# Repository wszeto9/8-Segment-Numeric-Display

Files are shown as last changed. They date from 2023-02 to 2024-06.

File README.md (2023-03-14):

# 8 Segment Numeric DIsplay

A 10W/digit numeric display to show numbers in any room. Designed for MIT 2.007's Spring gameboard. 

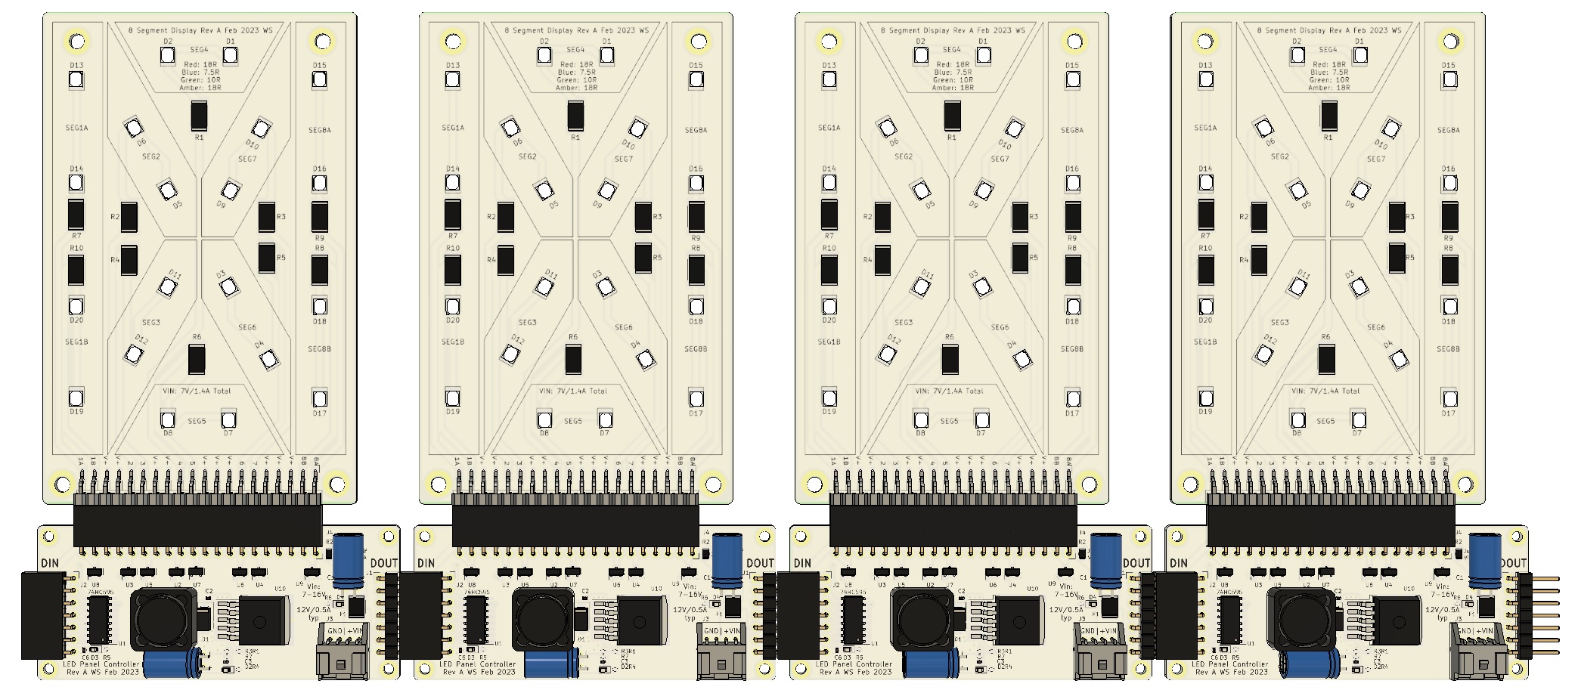
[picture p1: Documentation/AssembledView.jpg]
AssembledView


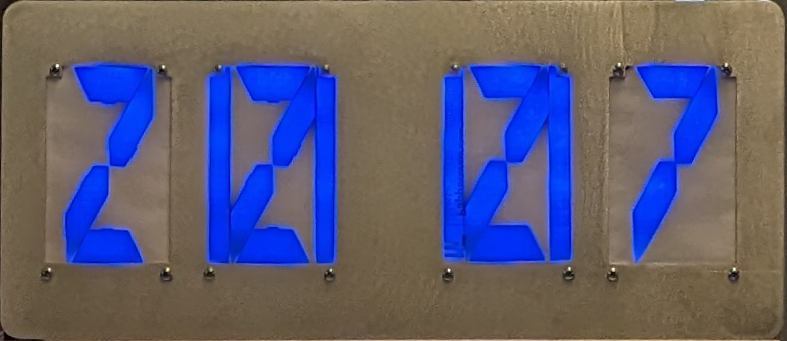
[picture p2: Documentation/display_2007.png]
2.007 Display

Display showing 2.007

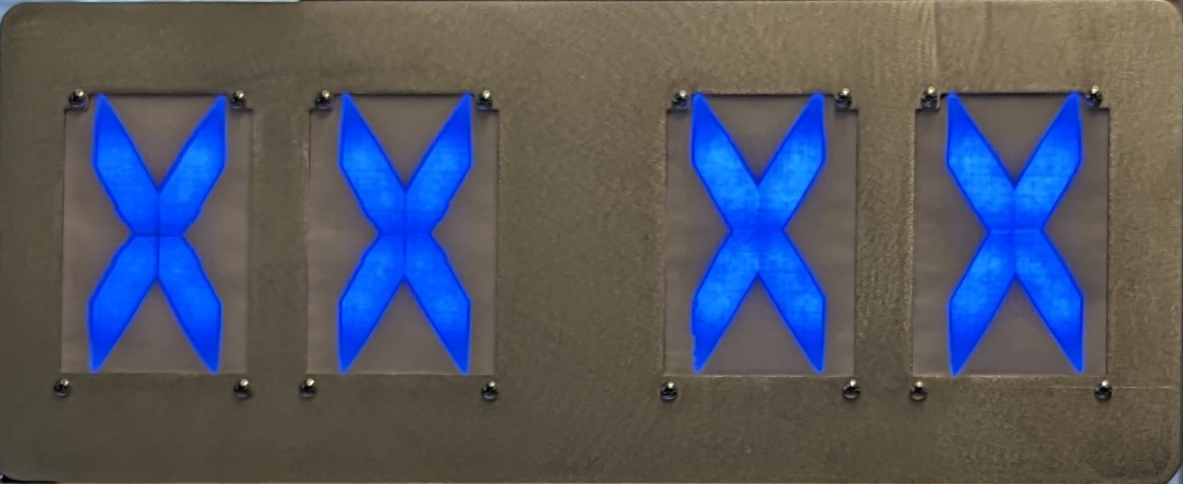
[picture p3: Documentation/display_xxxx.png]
xxxx Display

Display showing xx xx

[Interactive BOM for LED Display](https://htmlpreview.github.io/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)

[Interactive BOM for LED Display Controller](https://htmlpreview.github.io/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)

[Schematic for LED Display](https://github.com/wszeto9/8-Segment-Numeric-Display/blob/main/Documentation/LED_Panel_Sch.pdf)

[Schematic for LED Display Controller](https://github.com/wszeto9/8-Segment-Numeric-Display/blob/main/Documentation/LED_Panel_Controller_Sch.pdf)

The display is a 65mm x 102mm single layer aluminum PCB. It has a 1x20 SMT male header in order to connect a driver board. The display requires active cooling for duty cycles above 50%. 

The driver is a 75mm x 32mm double layer FR4 PCB. It relies on a 74HC595 shift register to drive a chain of displays using a single data stream. The driving microcontroller can send 3.3V or 5V logic. The logic level is set by the reference voltage on the input. The driver has an onboard buck converter to create the drive voltage of the display. The board can receive 7-28VDC (Peak current draw is 10W/Vin). 
 
# Driving Logic

- Pull nCLR high in order to prevent an accidential clear
- Use SRCLK and SER to send a data packet to the first number's data packet on the right (with LSB first)
- Repeat sending data until all numbers are sent.
- Pulse RCLK to push shifted bits into the outputs
- Use PWM on nOE to adjust the display brightness. Note: The brightness will lower with higher duty cycles.

|Number to display| Data packet|
|--|--|
|0|0b10111011|
|1|0b00000011|
|2|0b00111010|
|3|0b00011110|
|4|0b01000110|
|5|0b01011100|
|6|0b00101110|
|7|0b00110010|
|8|0b01111110|
|9|0b01110010|

# Ordering the LED Panel Parts

From Digikey: quantities are for 1x LED panel.

1x S1113E-20-ND

In addition,

**Red:**

- 20x 90-JE2835ARD-N-0001A0000-N0000001TR-ND

- 10x RMCF2512JT18R0CT-ND

**Blue:**

- 20x  90-JE2835ABL-N-0005A0000-N0000001CT-ND

- 10x 118-CRM2512-JW-6R8ELFCT-ND

**Yellow:**

- 20x 90-JE2835APA-N-0001A0000-N0000001CT-ND
- 10x RMCF2512JT18R0CT-ND

**Green:**
- 20x 90-JE2835AGR-N-0002A0000-N0000001CT-ND
- 10x RMCF2512JT10R0CT-ND

Resistance values for colors:

- Red: For 140mA (25.2lm/led) use 18R
- Amber: For 140mA (24.8lm/led) use 18R
- Green: For 140mA (65.5lm/led) use 10R
- Blue: For 140mA (16.5lm/led) use 6.8R

# Ordering the LED Panel Controller Parts

**Digikey Parts**
|Quantity|Digikey PN| Description|
|--|--|--|
|1|1189-3657-ND|120uF/35V Capacitor|
|1|399-ESK337M016AE3AA-ND|330uF/16V Capacitor|
|1|F3375CT-ND|2A Polyfuse|
|1|455-1849-ND|JST PA 1x04 RA Housing|
|1|455-2753-ND|JST PA 1x04 Connector|
|4|455-1325-1-ND|JST PA Crimp|
|1|1292-WR08X000PTLCT-ND|0805 Jumper|

**Amazon Parts**

- 1x [1x20 female pin socket](https://www.amazon.com/Yohii-Female-Header-2-54mm-Connector/dp/B07P1R9CGT/)

- 1x [LM2596 Buck Converter](https://www.amazon.com/gp/product/B0B63GQDJW/)

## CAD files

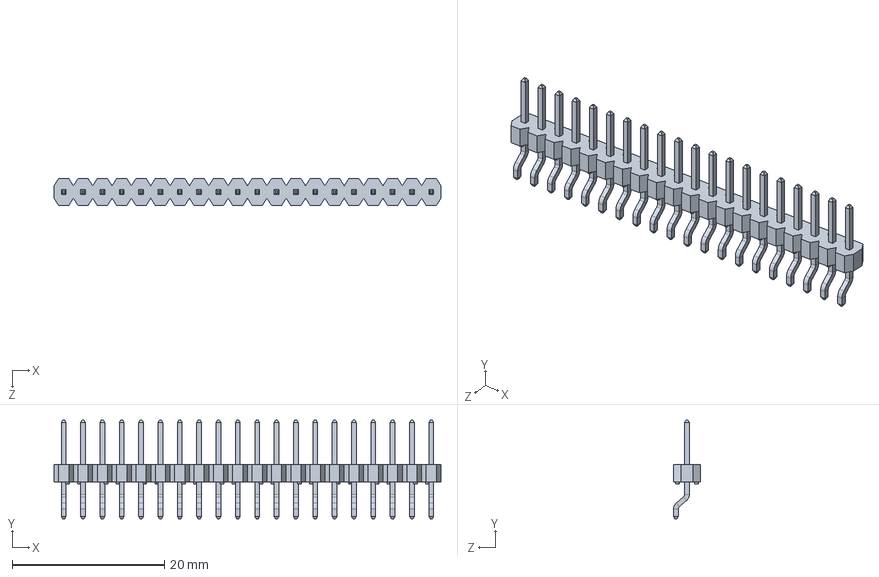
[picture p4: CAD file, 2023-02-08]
LED_Panel/C20SBSN-M89.step
50.8 x 13.0 x 3.56 mm

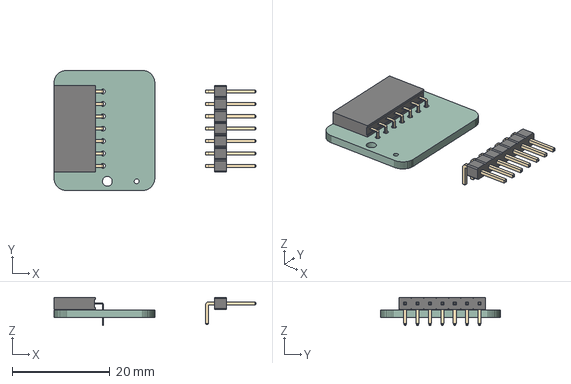
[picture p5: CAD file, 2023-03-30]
Spacer/Spacer.step
41.4 x 24.6 x 5.84 mm
PCB

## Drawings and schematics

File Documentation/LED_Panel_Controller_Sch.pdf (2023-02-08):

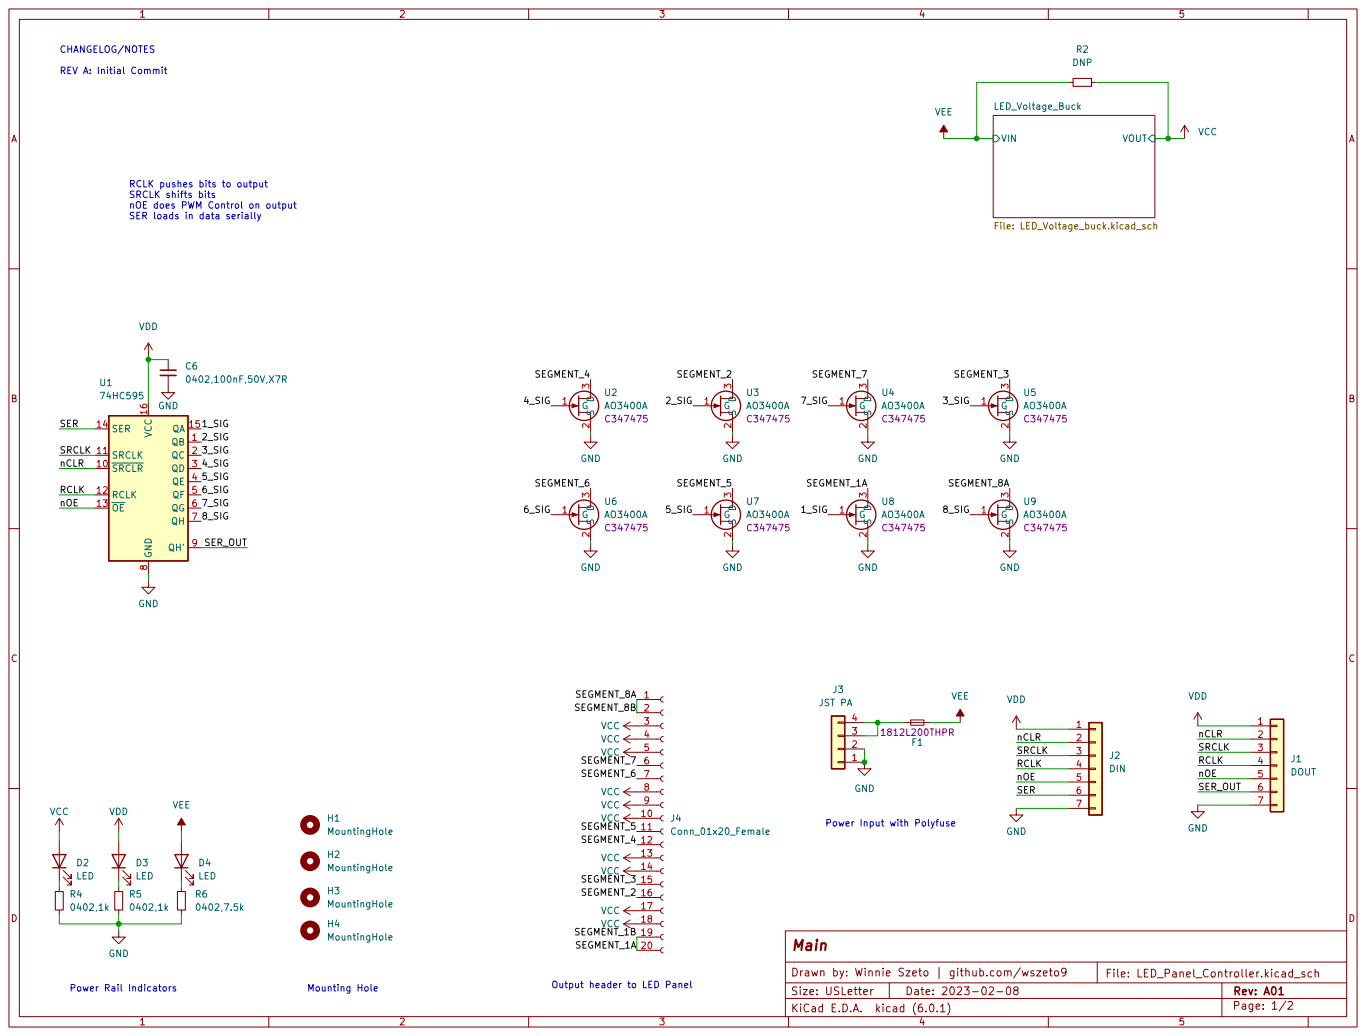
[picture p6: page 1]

CHANGELOG/NOTES REV A: Initial Commit

RCLK pushes bits to output SRCLK shifts bits nOE does PWM Control on output

SER loads in data serially
SEGMENT_5 SEGMENT_1B

Power Input with Polyfuse

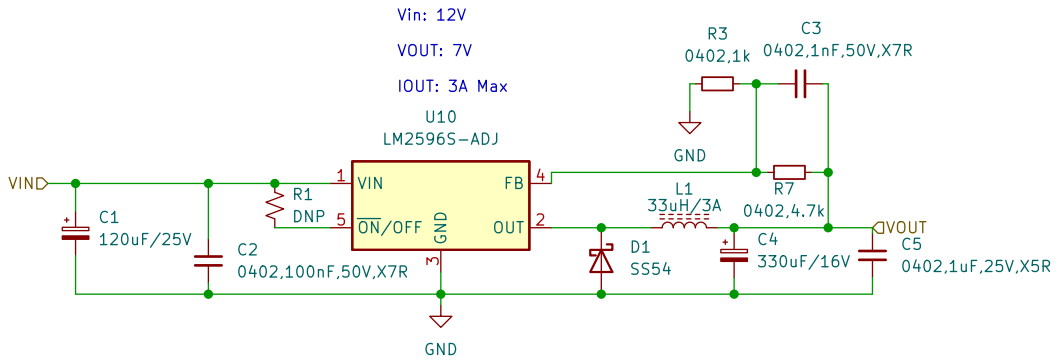
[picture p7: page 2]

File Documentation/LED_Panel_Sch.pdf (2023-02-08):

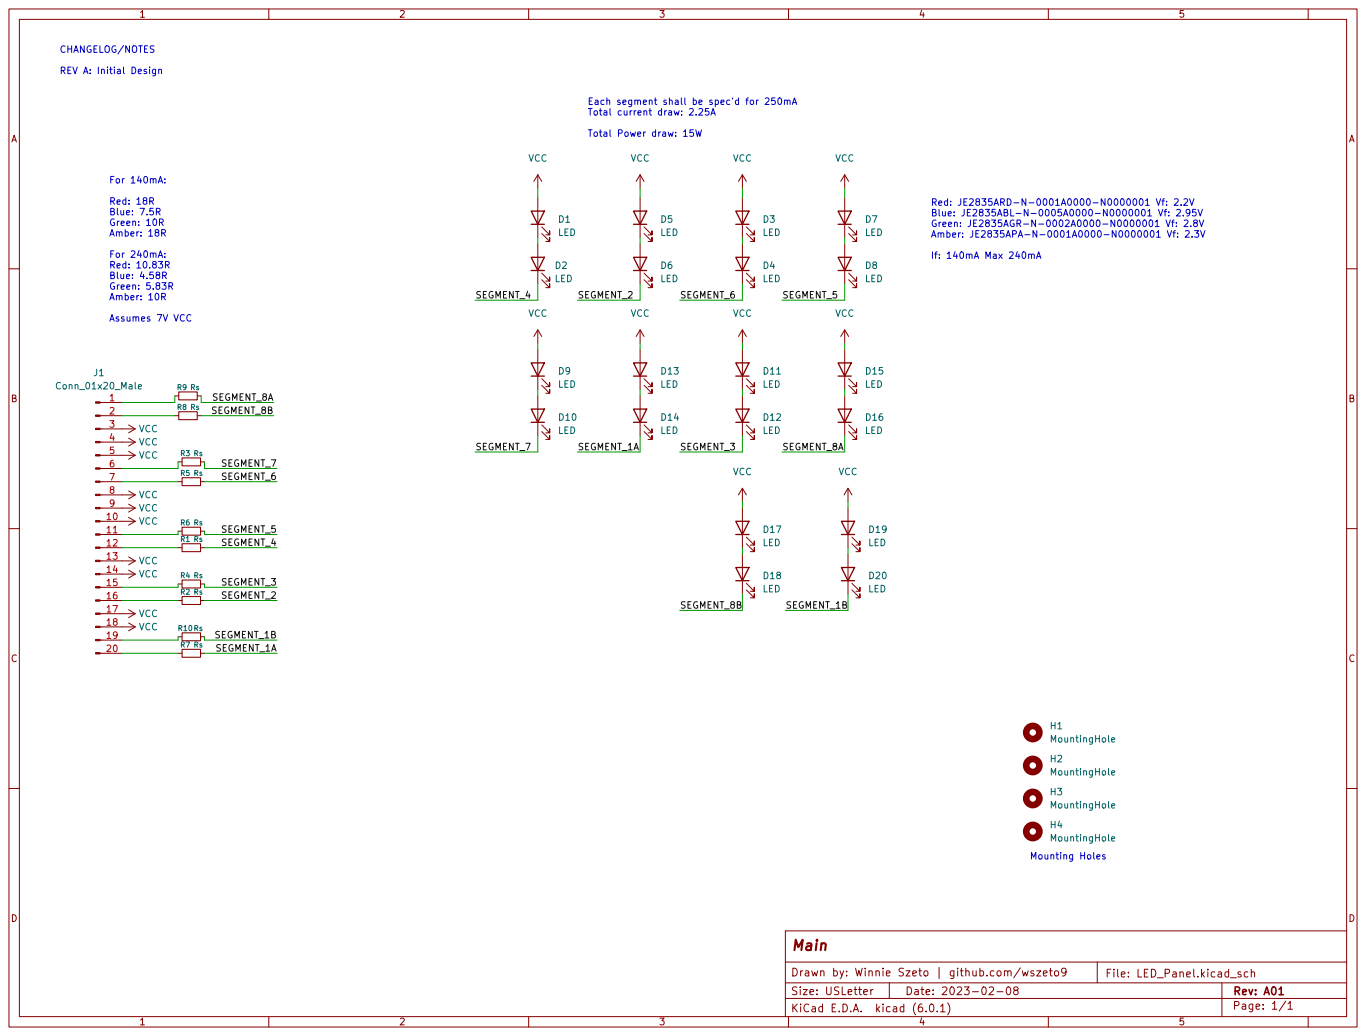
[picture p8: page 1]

CHANGELOG/NOTES REV A: Initial Design For 140mA: Red: 18R

Each segment shall be spec'd for 250mA
Total current draw: 2.25A
If: 140mA Max 240mA Mounting Holes

Red: JE2835ARD-N-0001A0000-N0000001 Vf: 2.2V
Blue: JE2835ABL-N-0005A0000-N0000001 Vf: 2.95V Green: JE2835AGR-N-0002A0000-N0000001 Vf: 2.8V

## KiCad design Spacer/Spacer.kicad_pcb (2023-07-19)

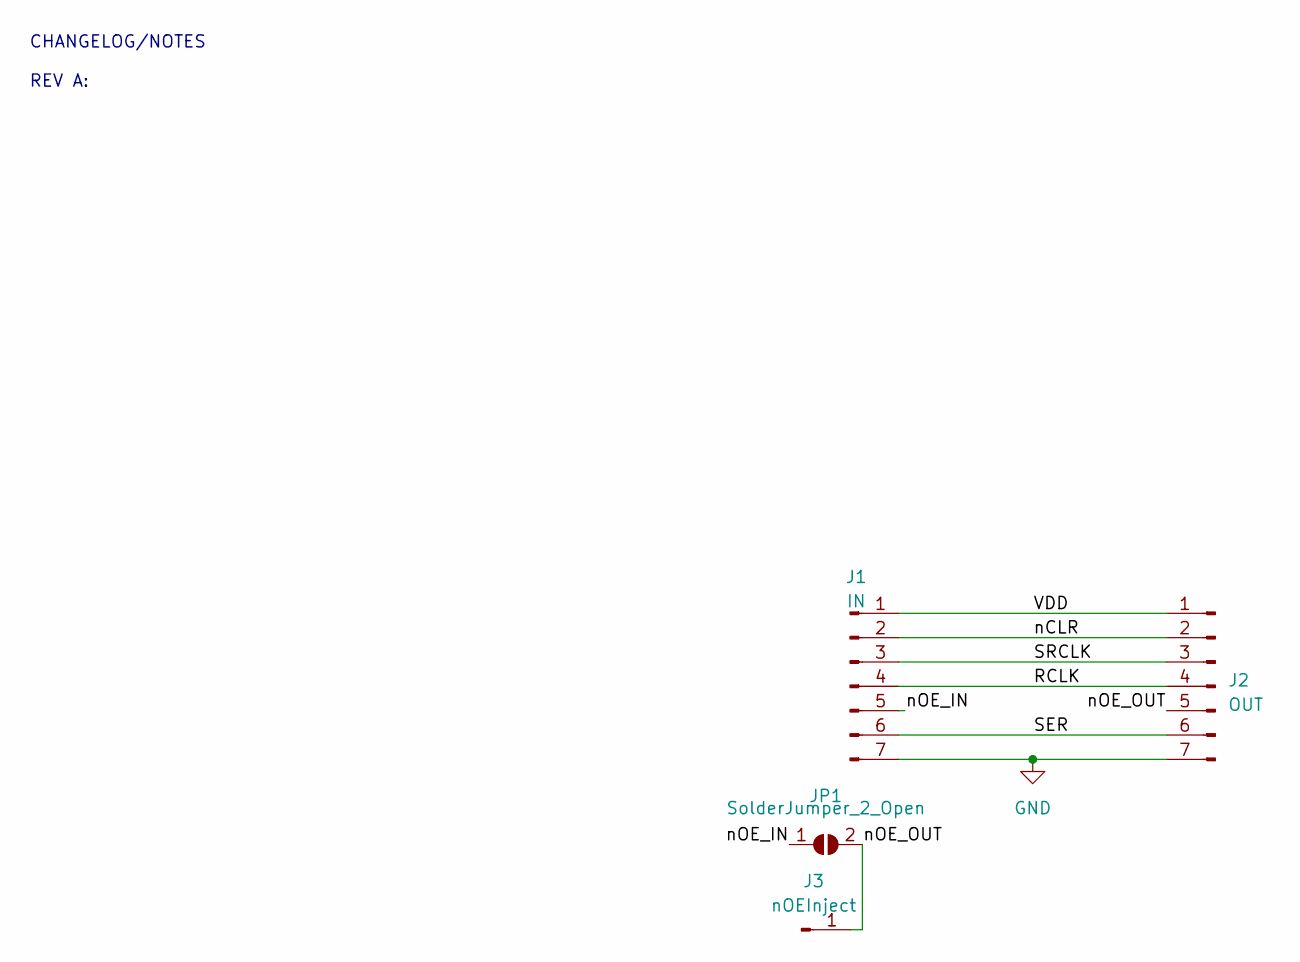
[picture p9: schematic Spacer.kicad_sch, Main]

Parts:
J1: IN; PinSocket_1x07_P2.54mm_Horizontal
J2: OUT; PinHeader_1x07_P2.54mm_Horizontal
J3: nOEInject; SolderWire-0.1sqmm_1x01_D0.4mm_OD1mm_Relief2x
JP1: SolderJumper_2_Open; SolderJumper-2_P1.3mm_Open_TrianglePad1.0x1.5mm

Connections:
/RCLK: J1.4, J2.4
/SER: J1.6, J2.6
/SRCLK: J1.3, J2.3
/VDD: J1.1, J2.1
/nCLR: J1.2, J2.2
/nOE_IN: J1.5, JP1.1 (A)
/nOE_OUT: J2.5, J3.1, JP1.2 (B)
GND: J1.7, J2.7

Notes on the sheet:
CHANGELOG/NOTES REV A:

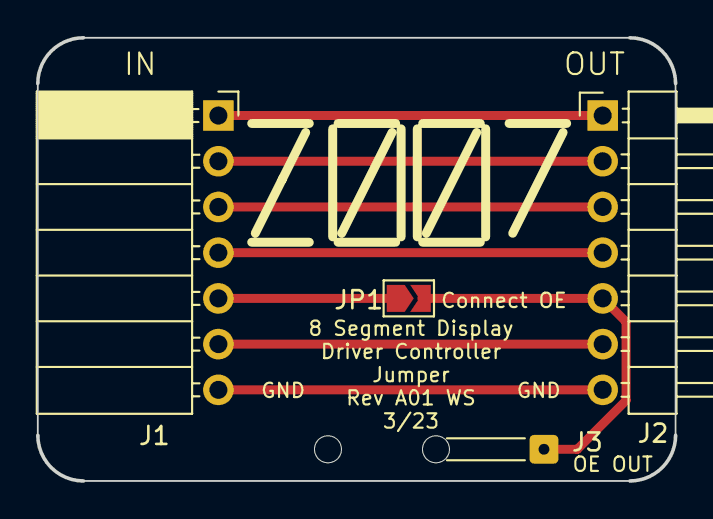
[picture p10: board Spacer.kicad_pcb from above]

Board: 2 copper layers, 35.4 x 24.6 mm, 4 parts (0 on the bottom side), 8 nets.

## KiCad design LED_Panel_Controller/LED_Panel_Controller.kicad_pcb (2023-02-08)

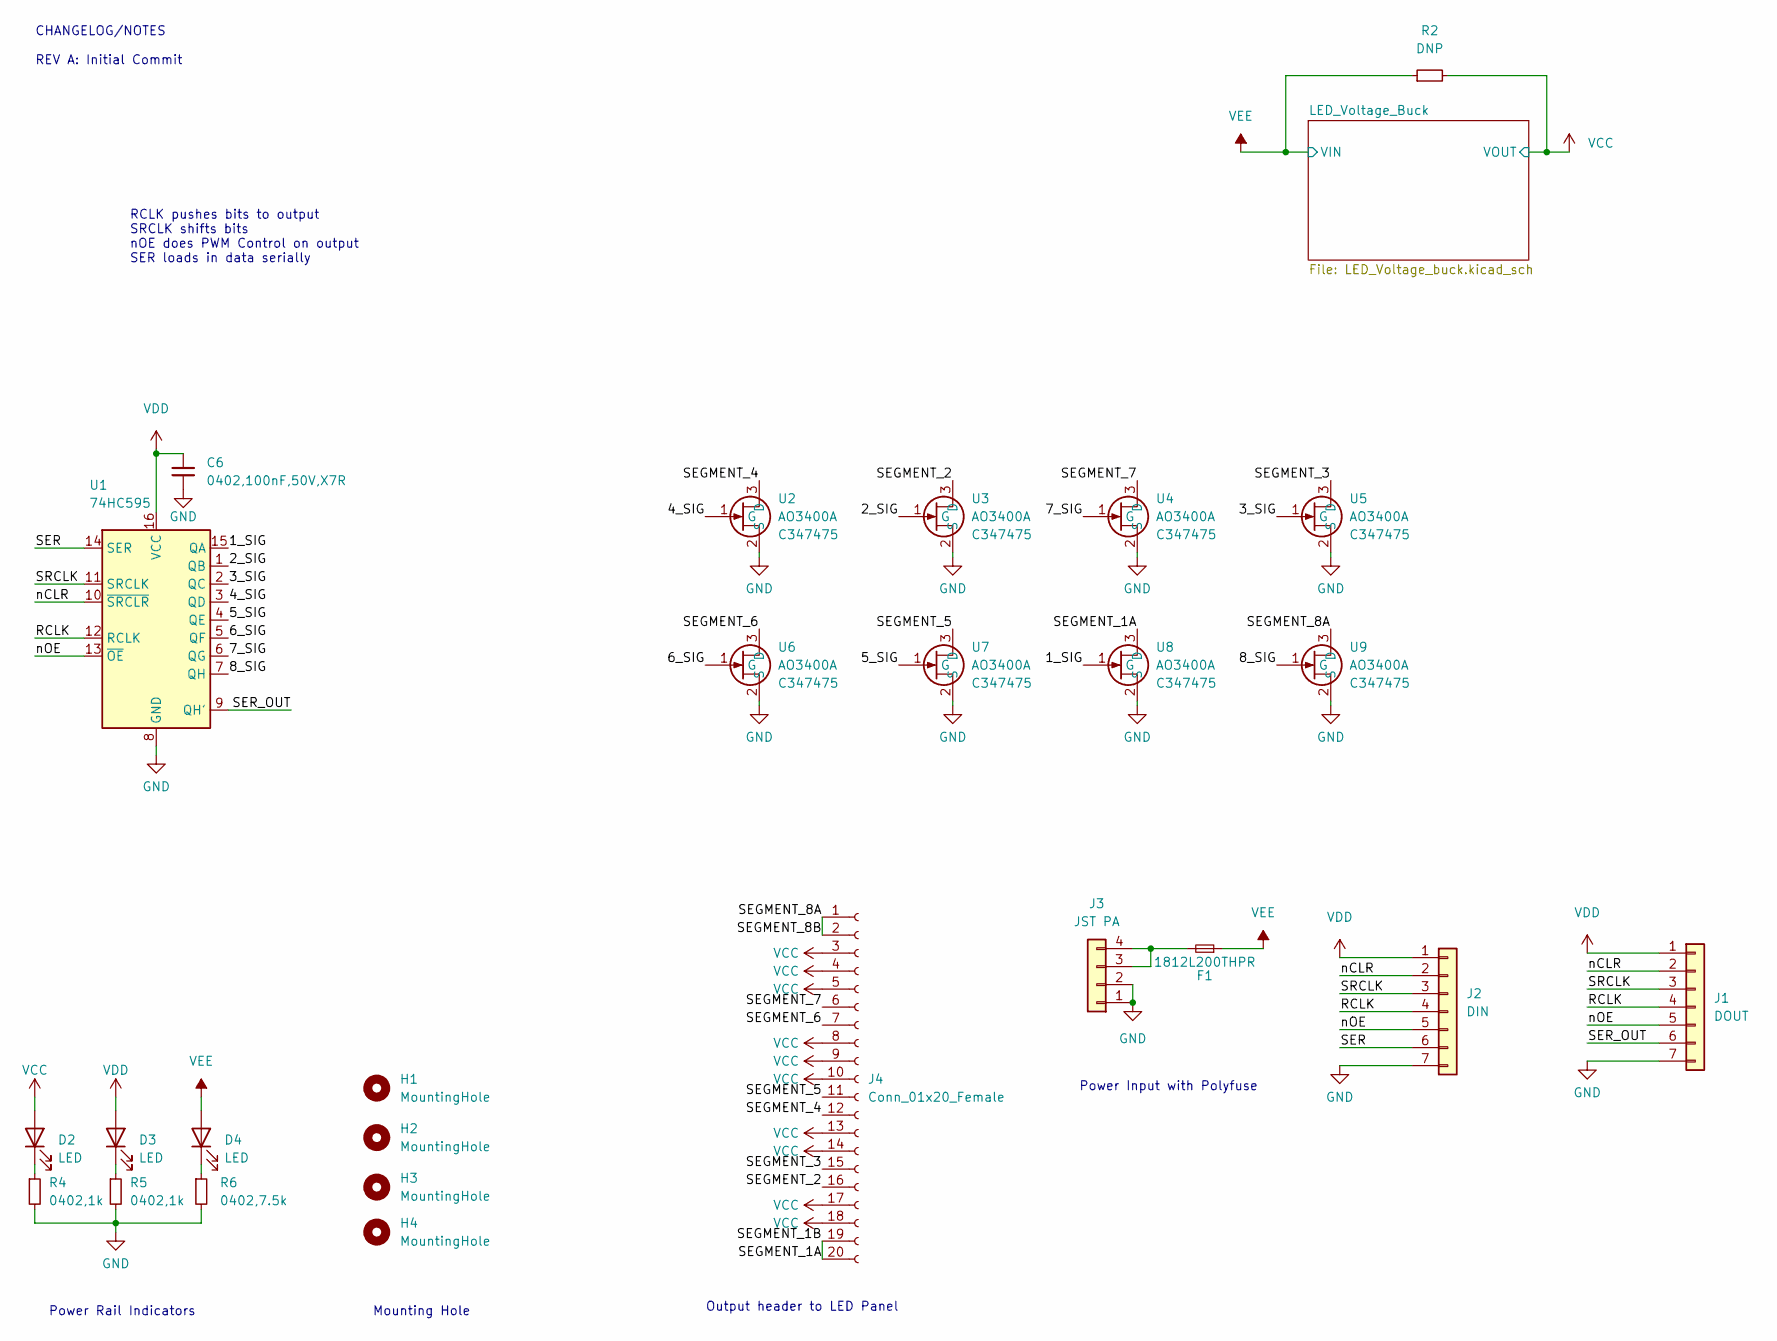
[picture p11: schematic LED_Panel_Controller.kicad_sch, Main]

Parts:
C6: 0402,100nF,50V,X7R; C_0402_1005Metric; MFGPN CL05B104KB54PNC; LCSC C307331
D2, D3, D4: LED; LED_0603_1608Metric; LCSC C2290
F1: 3A; Fuse_1812_4532Metric; MFGPN 1812L200THPR; Digikey F3375CT-ND
H1, H2, H3, H4: MountingHole; MountingHole_2.2mm_M2_DIN965_Pad
J1: DOUT; PinHeader_1x07_P2.54mm_Horizontal
J2: DIN; PinSocket_1x07_P2.54mm_Horizontal
J3: JST PA; JST_S04B-PASK-2(LF)(SN); Digikey 455-1849-ND
J4: Conn_01x20_Female; PinSocket_1x20_P2.54mm_Horizontal
R2: DNP; R_0805_2012Metric
R4, R5: 0402,1k; R_0402_1005Metric; MFGPN 0402WGF1001TCE; LCSC C11702
R6: 0402,7.5k; R_0402_1005Metric; MFGPN 0402WGF7501TCE; LCSC C25918
U1: 74HC595; SOIC-16_3.9x9.9mm_P1.27mm; MFGPN CD74HC595M96; LCSC C5947
U2, U3, U4, U5, U6, U7, U8, U9: AO3400A; SOT-23; LCSC C347475

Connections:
/1_SIG: U1.15 (QA), U8.1 (G)
/2_SIG: U1.1 (QB), U3.1 (G)
/3_SIG: U1.2 (QC), U5.1 (G)
/4_SIG: U1.3 (QD), U2.1 (G)
/5_SIG: U1.4 (QE), U7.1 (G)
/6_SIG: U1.5 (QF), U6.1 (G)
/7_SIG: U1.6 (QG), U4.1 (G)
/8_SIG: U1.7 (QH), U9.1 (G)
/RCLK: J1.4, J2.4, U1.12 (RCLK)
/SEGMENT_1A: J4.19, J4.20, U8.3 (D)
/SEGMENT_2: J4.16, U3.3 (D)
/SEGMENT_3: J4.15, U5.3 (D)
/SEGMENT_4: J4.12, U2.3 (D)
/SEGMENT_5: J4.11, U7.3 (D)
/SEGMENT_6: J4.7, U6.3 (D)
/SEGMENT_7: J4.6, U4.3 (D)
/SEGMENT_8A: J4.1, J4.2, U9.3 (D)
/SER: J2.6, U1.14 (SER)
/SER_OUT: J1.6, U1.9 (QH')
/SRCLK: J1.3, J2.3, U1.11 (SRCLK)
/nCLR: J1.2, J2.2, U1.10 (~SRCLR)
/nOE: J1.5, J2.5, U1.13 (~OE)
GND: C6.2, J1.7, J2.7, J3.1, J3.2, R4.2, R5.2, R6.2, U1.8 (GND), U2.2 (S), U3.2 (S), U4.2 (S), U5.2 (S), U6.2 (S), U7.2 (S), U8.2 (S), U9.2 (S); also elsewhere on the board
unnamed: D2.1 (K), R4.1
unnamed: D3.1 (K), R5.1
unnamed: D4.1 (K), R6.1
unnamed: F1.2, J3.3, J3.4
VCC: D2.2 (A), J4.3, J4.4, J4.5, J4.8, J4.9, J4.10, J4.13, J4.14, J4.17, J4.18, R2.2; also elsewhere on the board
VDD: C6.1, D3.2 (A), J1.1, J2.1, U1.16 (VCC)
VEE: D4.2 (A), F1.1, R2.1; also elsewhere on the board

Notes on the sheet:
Power Input with Polyfuse
RCLK pushes bits to output SRCLK shifts bits nOE does PWM Control on output SER loads in data serially
Mounting Hole
Output header to LED Panel
Power Rail Indicators
CHANGELOG/NOTES REV A: Initial Commit

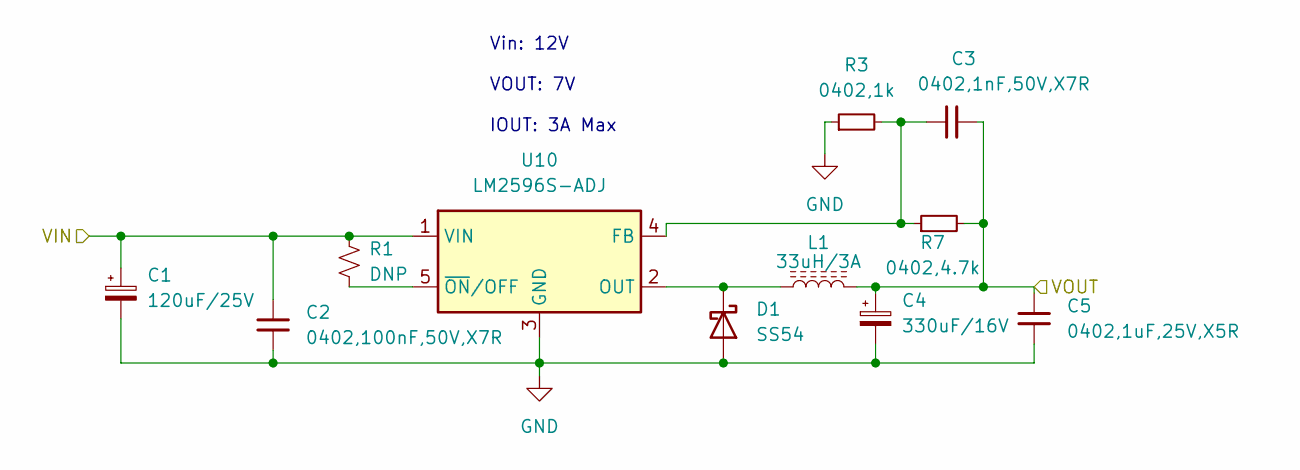
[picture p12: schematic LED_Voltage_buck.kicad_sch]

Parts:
C1: 120uF/25V; C_Radial_D6.3mm_H11.0mm_P2.50mm; MFGPN 860010473009; Digikey 732-8632-1-ND
C2: 0402,100nF,50V,X7R; C_0402_1005Metric; MFGPN CL05B104KB54PNC; LCSC C307331
C3: 0402,1nF,50V,X7R; C_0402_1005Metric; MFGPN 0402B102K500NT; LCSC C1523
C4: 330uF/16V; C_Radial_D6.3mm_H11.0mm_P2.50mm; MFGPN 860020373011; Digikey 732-8798-1-ND
C5: 0402,1uF,25V,X5R; C_0402_1005Metric; MFGPN CL05A105KA5NQNC; LCSC C52923
D1: SS54; D_SMA; LCSC C22452
L1: 33uH/3A; L_10.4x10.4_H4.8; LCSC C225031
R1: DNP; R_0402_1005Metric
R3: 0402,1k; R_0402_1005Metric; MFGPN 0402WGF1001TCE; LCSC C11702
R7: 0402,4.7k; R_0402_1005Metric; MFGPN 0402WGF4701TCE; LCSC C25900
U10: LM2596S-ADJ; TO-263-5_TabPin3; MFGPN LM2596S-ADJ

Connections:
GND: C1.2, C2.2, C4.2, C5.2, D1.2 (A), R3.1, U10.3 (GND); also elsewhere on the board
unnamed: C3.1, R3.2, R7.1, U10.4 (FB)
unnamed: D1.1 (K), L1.1, U10.2 (OUT)
unnamed: R1.1, U10.5 (~ON/OFF)
VCC: C3.2, C4.1, C5.1, L1.2, R7.2; also elsewhere on the board
VEE: C1.1, C2.1, R1.2, U10.1 (VIN); also elsewhere on the board

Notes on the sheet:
Vin: 12V VOUT: 7V IOUT: 3A Max

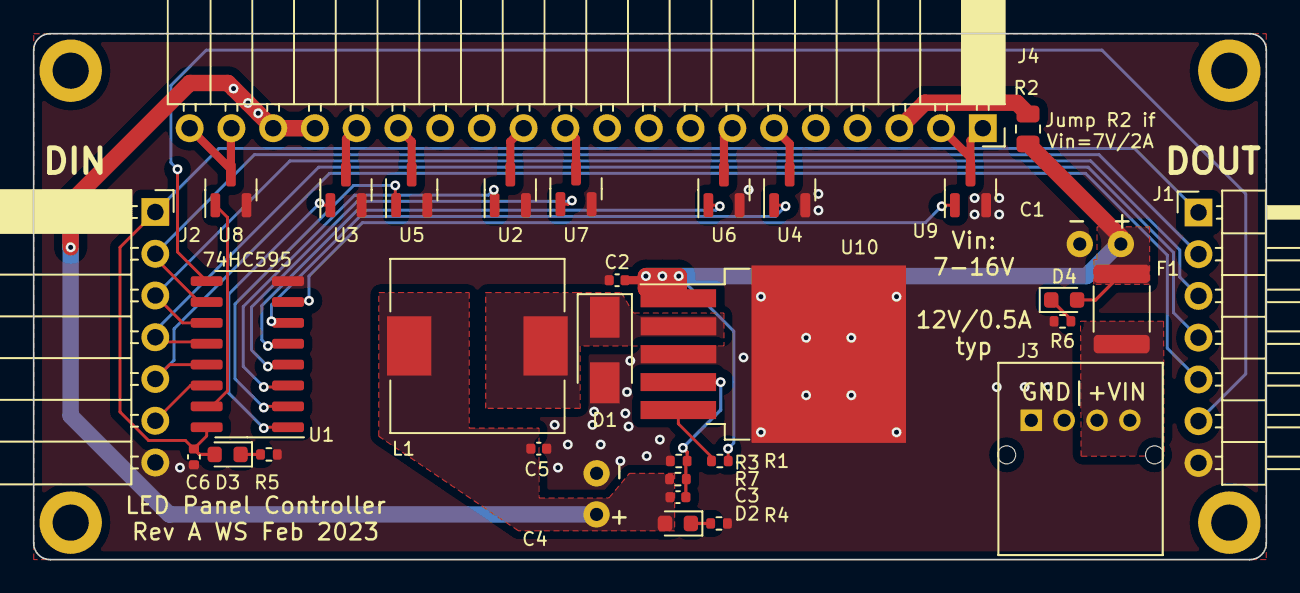
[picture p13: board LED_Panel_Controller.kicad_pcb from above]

Board: 2 copper layers, 75.0 x 32.0 mm, 37 parts (0 on the bottom side), 33 nets.

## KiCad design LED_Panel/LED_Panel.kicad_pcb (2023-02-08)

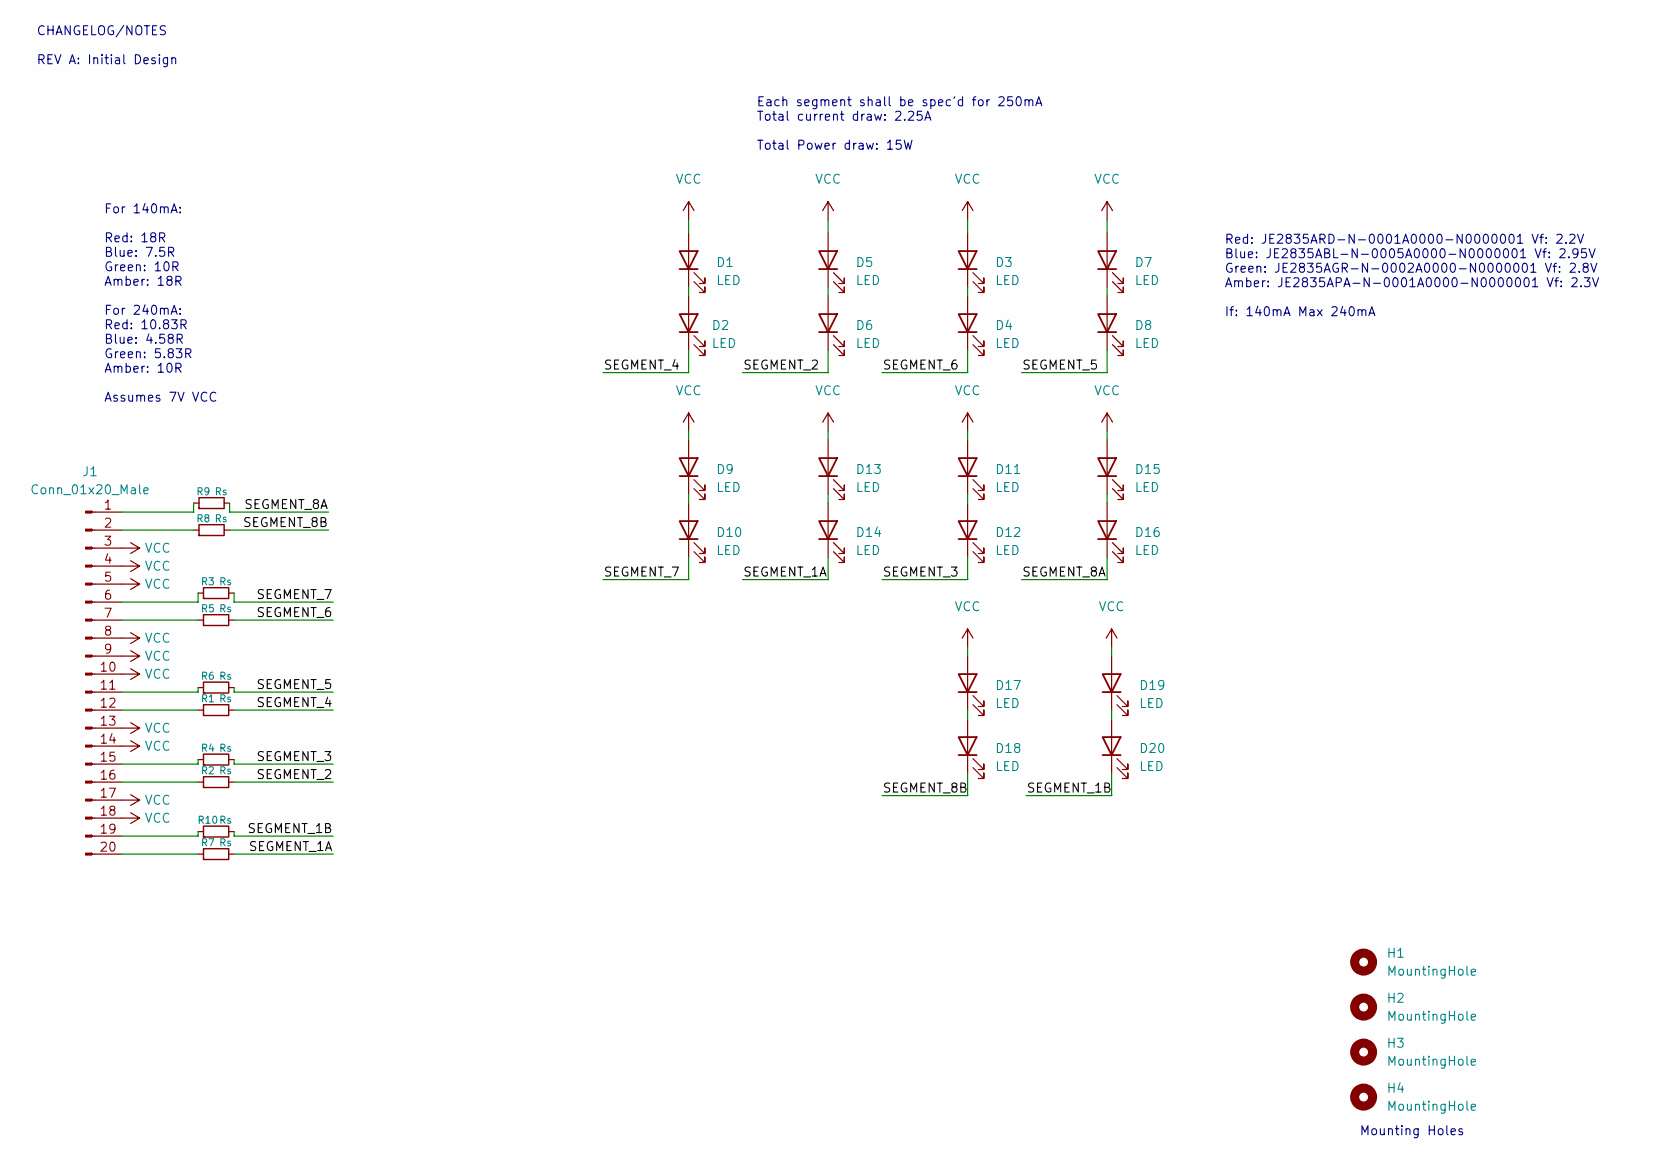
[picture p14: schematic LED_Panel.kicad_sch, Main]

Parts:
D1, D2, D3, D4, D5, D6, D7, D8, D9, D10, D11, D12, D13, D14, D15, D16, D17, D18, D19, D20: LED; LED_PLCC_2835
H1, H2, H3, H4: MountingHole; MountingHole_3.2mm_M3_DIN965_Pad
J1: Conn_01x20_Male; Harwin_M20-89020xx_1x20_P2.54mm_Horizontal; Digikey S1113E-20-ND
R1, R2, R3, R4, R5, R6, R7, R8, R9, R10: Rs; R_2512_6332Metric

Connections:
/SEGMENT_1A: D14.1 (K), R7.2
/SEGMENT_1B: D20.1 (K), R10.2
/SEGMENT_2: D6.1 (K), R2.2
/SEGMENT_3: D12.1 (K), R4.2
/SEGMENT_4: D2.1 (K), R1.2
/SEGMENT_5: D8.1 (K), R6.2
/SEGMENT_6: D4.1 (K), R5.2
/SEGMENT_7: D10.1 (K), R3.2
/SEGMENT_8A: D16.1 (K), R9.2
/SEGMENT_8B: D18.1 (K), R8.2
unnamed: D1.1 (K), D2.2 (A)
unnamed: D3.1 (K), D4.2 (A)
unnamed: D5.1 (K), D6.2 (A)
unnamed: D7.1 (K), D8.2 (A)
unnamed: D9.1 (K), D10.2 (A)
unnamed: D11.1 (K), D12.2 (A)
unnamed: D13.1 (K), D14.2 (A)
unnamed: D15.1 (K), D16.2 (A)
unnamed: D17.1 (K), D18.2 (A)
unnamed: D19.1 (K), D20.2 (A)
unnamed: J1.1, R9.1
unnamed: J1.2, R8.1
unnamed: J1.6, R3.1
unnamed: J1.7, R5.1
unnamed: J1.11, R6.1
unnamed: J1.12, R1.1
unnamed: J1.15, R4.1
unnamed: J1.16, R2.1
unnamed: J1.19, R10.1
unnamed: J1.20, R7.1
VCC: D1.2 (A), D3.2 (A), D5.2 (A), D7.2 (A), D9.2 (A), D11.2 (A), D13.2 (A), D15.2 (A), D17.2 (A), D19.2 (A), J1.3, J1.4, J1.5, J1.8, J1.9, J1.10, J1.13, J1.14, J1.17, J1.18

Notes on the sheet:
Mounting Holes
Red: JE2835ARD-N-0001A0000-N0000001 Vf: 2.2V Blue: JE2835ABL-N-0005A0000-N0000001 Vf: 2.95V Green: JE2835AGR-N-0002A0000-N0000001 Vf: 2.8V Amber: JE2835APA-N-0001A0000-N0000001 Vf: 2.3V If: 140mA Max 240mA
Each segment shall be spec'd for 250mA Total current draw: 2.25A Total Power draw: 15W
For 140mA: Red: 18R Blue: 7.5R Green: 10R Amber: 18R For 240mA: Red: 10.83R Blue: 4.58R Green: 5.83R Amber: 10R Assumes 7V VCC
CHANGELOG/NOTES REV A: Initial Design

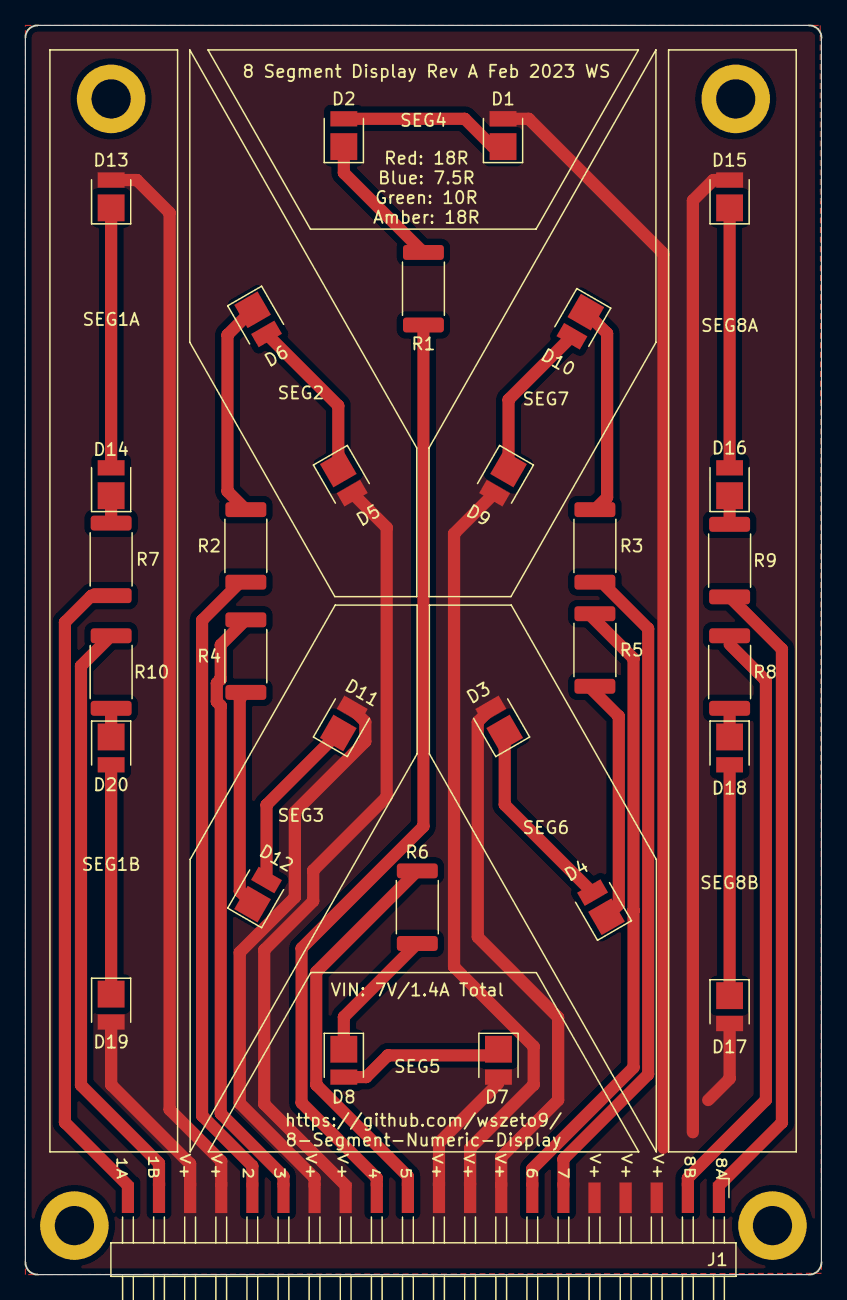
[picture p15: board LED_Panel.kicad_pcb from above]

Board: 2 copper layers, 65.0 x 102.0 mm, 35 parts (0 on the bottom side), 31 nets.

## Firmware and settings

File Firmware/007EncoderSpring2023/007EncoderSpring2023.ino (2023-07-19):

/*
Written February 2023, Winnie Szeto

For 2.007's gameboard.

Inputs: two single-channel encoders 
Output: 4-digit display on a 74HC595 shift register,
        2 Servos to control ball release
###################################################################
Initialize all variables associated with counting the encoder ticks
###################################################################
 */

#include <Servo.h>

Servo servoInner;
Servo servoOuter;

#define servoInnerPin 5
#define servoOuterPin 4

//change based on gameboard color
//#define blueGameboard 1
//d#define redGameboard 1
//#define greenGameboard 1
#define yellowGameboard 1


#ifdef blueGameboard
#define servoInnerEngagedPos 90
#define servoInnerDisengagedPos 130
#define servoInnerDelayms 400

#define servoOuterEngagedPos 110
#define servoOuterDisengagedPos 0
#define servoOuterDelayms 550

#define isOnLeftSide 0
#endif


#ifdef redGameboard
#define servoInnerEngagedPos 120
#define servoInnerDisengagedPos 70
#define servoInnerDelayms 550

#define servoOuterEngagedPos 110
#define servoOuterDisengagedPos 0
#define servoOuterDelayms 550

#define isOnLeftSide 1
#endif


#ifdef greenGameboard
#define servoInnerEngagedPos 100
#define servoInnerDisengagedPos 160
#define servoInnerDelayms 550

#define servoOuterEngagedPos 110
#define servoOuterDisengagedPos 20
#define servoOuterDelayms 590

#define isOnLeftSide 0
#endif


#ifdef yellowGameboard
#define servoInnerEngagedPos 90
#define servoInnerDisengagedPos 35
#define servoInnerDelayms 550

#define servoOuterEngagedPos 110
#define servoOuterDisengagedPos 180
#define servoOuterDelayms 650

#define isOnLeftSide 1
#endif


#define DEBUG_MODE 1

#define PI 3.14159

#define encoderOuter 2
#define encoderInner 3
//Encoders are attached to the nano's INT pins

#define EncoderTicks 20
//ticks are defined as the number of pulses/revolution

#define AveragingSamples 3

unsigned long previousEncoderTimeOuter = 0;
unsigned long previousEncoderTimeInner = 0;
//time references to calculate speed

//time references to calculate if it's been 5 seconds in a bucket
unsigned long newBucketTimeOuter = 0;
unsigned long newBucketTimeInner = 0;

int OuterAverageVelocity;
int InnerAverageVelocity;

int InnerVelocities[AveragingSamples]; 
int OuterVelocities[AveragingSamples];

int SpeedBins[] = {0,25,51,101,151,201,251};
int pointBinsInner[] = {0,5,10,20,40,47,99};
int pointBinsOuter[] = {0,3,7,15,21,26,99};

uint8_t currentBucketOuter = 0;
uint8_t currentBucketInner = 0;

uint8_t previousBucketOuter = 0;
uint8_t previousBucketInner = 0;

uint8_t maxBucketOuter = 0;
uint8_t maxBucketInner = 0;
  
/*
###################################################################
Initialize all variables associated with the shift register display
###################################################################
 */

#define MAX_BRIGHTNESS 25 //out of 255

#define SER 12
#define nOE 11
#define RCLK 10
#define SRCLK 9
#define nCLR 8
#define nOE_RIGHT 6


//displayData[number] will return the data to display the number
uint8_t displayData[] ={ 
0b10111011,
0b00000011,
0b00111010,
0b00011110,
0b01000110,
0b01011100,
0b00101110,
0b00110010,
0b01111110,
0b01100110
};


#define buttonUpper A1
#define buttonLower A5

/*
#######################################################
Function declaration
########################################################
 */
//Function will update Outer/Inner angular velocity if accel<maxaccel
void CalculateEncoderTimeOuter(){
    unsigned long elapsedTime = micros() - previousEncoderTimeOuter;
    previousEncoderTimeOuter = micros();
    //calculates elapsed time, resets previous time reference to new time

    //does averaging maths
    unsigned long sum = 0;
    for(int k = AveragingSamples-1; k > 0; k+= -1){
      OuterVelocities[k] = OuterVelocities[k-1]; 
      sum += OuterVelocities[k];
    }

    //add new sample to velocities
    OuterVelocities[0] = (float)1000000* 60 / EncoderTicks * 1/elapsedTime;
    sum += OuterVelocities[0];
    OuterAverageVelocity = sum / AveragingSamples;

    //convert velocity into point bucket
    previousBucketOuter = currentBucketOuter;
    for(int i = 0;i<7;i++){
      if(OuterAverageVelocity > SpeedBins[i]){
        currentBucketOuter = i;
      }
    }
    if(currentBucketOuter != previousBucketOuter){
      newBucketTimeOuter = millis();  
    }

}


void CalculateEncoderTimeInner(){
    unsigned long elapsedTime = micros() - previousEncoderTimeInner;
    previousEncoderTimeInner = micros();
    //calculates elapsed time, resets previous time reference to new time

    //does averaging maths
    unsigned long sum = 0;
    for(int k = AveragingSamples-1; k > 0; k+= -1){
      InnerVelocities[k] = InnerVelocities[k-1]; 
      sum += InnerVelocities[k];
    }

    //add new sample to velocities
    InnerVelocities[0] = (float)1000000* 60 / EncoderTicks * 1/elapsedTime;
    sum += InnerVelocities[0];
    InnerAverageVelocity = sum / AveragingSamples;

    //convert velocity into point bucket
    previousBucketInner = currentBucketInner;
    for(int i = 0;i<7;i++){
      if(InnerAverageVelocity > SpeedBins[i]){
        currentBucketInner = i;
      }
    }
    if(currentBucketInner != previousBucketInner){
      newBucketTimeInner = millis();  
    }

}


//function inputs a 4 digit number and pushes it to the display panel
void DisplayNumber(int numberToDisplay){
  int firstDigit = numberToDisplay % 10;
  int secondDigit = ((numberToDisplay % 100) - firstDigit)/10;
  int thirdDigit = ((numberToDisplay % 1000 - (secondDigit*10)) - firstDigit)/100;
  int fourthDigit = (numberToDisplay - (thirdDigit * 100) - (secondDigit * 10) - firstDigit)/1000;
  //shift data to 595
  shiftOut(SER, SRCLK, LSBFIRST, displayData[firstDigit]);
  shiftOut(SER, SRCLK, LSBFIRST, displayData[secondDigit]);
  shiftOut(SER, SRCLK, LSBFIRST, displayData[thirdDigit]);
  shiftOut(SER, SRCLK, LSBFIRST, displayData[fourthDigit]);
  //push data to storage register
  digitalWrite(RCLK, HIGH);
  delayMicroseconds(100);
  digitalWrite(RCLK, LOW);
}

void setup() {
  pinMode(buttonLower, INPUT_PULLUP);
  pinMode(buttonUpper, INPUT_PULLUP);
  
  pinMode(7, OUTPUT);
  digitalWrite(7, HIGH);
  pinMode(encoderOuter, INPUT_PULLUP);
  pinMode(encoderInner, INPUT_PULLUP);
  previousEncoderTimeOuter = millis();
  previousEncoderTimeInner = millis();
  attachInterrupt(digitalPinToInterrupt(encoderOuter), CalculateEncoderTimeOuter, RISING);
  attachInterrupt(digitalPinToInterrupt(encoderInner), CalculateEncoderTimeInner, RISING);

  pinMode(nOE, OUTPUT);
  pinMode(nOE_RIGHT, OUTPUT);
  pinMode(nCLR, OUTPUT);
  pinMode(SER, OUTPUT);
  pinMode(RCLK, OUTPUT);
  pinMode(SRCLK, OUTPUT);
  
  digitalWrite(nCLR, HIGH);
  analogWrite(nOE, 255-MAX_BRIGHTNESS);


  servoInner.attach(servoInnerPin);
  servoOuter.attach(servoOuterPin);

  servoOuter.write(servoOuterEngagedPos);
  servoInner.write(servoInnerEngagedPos);
  if(DEBUG_MODE){
    Serial.begin(115200);
  }

}

void loop() {

  //sets velocity to 0 if no encoder ticks were detected in the past second
  if(micros() - previousEncoderTimeOuter > 1000000){
    currentBucketOuter = 0;
    if(OuterAverageVelocity > 300){
    OuterAverageVelocity = 0;
    } 
    if(OuterAverageVelocity > 0){
    OuterAverageVelocity = OuterAverageVelocity -1;
    }  
    for(int k = 0; k < AveragingSamples; k++){
      OuterVelocities[k] = 0;
    }
  } 
  
  if(micros() - previousEncoderTimeInner > 1000000){
    currentBucketInner = 0;
    if(InnerAverageVelocity > 1000){
      InnerAverageVelocity = 0;
    }
    if(InnerAverageVelocity > 0){
      InnerAverageVelocity = InnerAverageVelocity -1;
    }
    for(int k = 0; k < AveragingSamples; k++){
      InnerVelocities[k] = 0;
    }  
  } 

  if(!digitalRead(buttonLower) || ((millis() - newBucketTimeOuter > 5000) && currentBucketOuter > 0)){ //if it's been at a bucket for 5s and the bucket is nonzero
    newBucketTimeOuter = millis();//reset 5s time reference
    if(maxBucketOuter < currentBucketOuter){ //update the max bucket if needed
      maxBucketOuter = currentBucketOuter;
    }
    
    servoOuter.write(servoOuterDisengagedPos);
    delay(servoOuterDelayms);
    servoOuter.write(servoOuterEngagedPos);   
  }

  if(!digitalRead(buttonUpper) || ((millis() - newBucketTimeInner > 5000) && currentBucketInner > 0)){ //if it's been at a bucket for 5s and the bucket is nonzero
    newBucketTimeInner = millis();//reset 5s time reference
    if(maxBucketInner < currentBucketInner){ //update the max bucket if needed
      maxBucketInner = currentBucketInner;
    }
    
    servoInner.write(servoInnerDisengagedPos);
    delay(servoInnerDelayms);
    servoInner.write(servoInnerEngagedPos);    
  }
  
  if(DEBUG_MODE){
    Serial.print("Current_bucket:");
    Serial.print(currentBucketOuter);
    Serial.print(",TimAtCurrentOuterBucket(s):");
    Serial.print((millis() - newBucketTimeOuter)/1000);
    Serial.print(",OuterAverageVelocity:");
    Serial.print(OuterAverageVelocity);
    Serial.print(",OuterPointsDisplayed:");
    Serial.print(pointBinsOuter[maxBucketOuter]);
    Serial.print(",InnerAverageVelocity:");
    Serial.print(InnerAverageVelocity);
    Serial.print(",InnerPointsDisplayed:");
    Serial.println(pointBinsInner[maxBucketInner]);
  }

  
  if(isOnLeftSide){
    DisplayNumber(pointBinsOuter[maxBucketOuter] * 100 + pointBinsInner[maxBucketInner]);
  }
  else{
    DisplayNumber(pointBinsInner[maxBucketInner] * 100 + pointBinsOuter[maxBucketOuter]);
  }
  
  //for (int i = 0; i <= 9; i++) {
    //DisplayNumber(1111 * i);
    //delay(100);
 // }
 
  if(isOnLeftSide){
    analogWrite(nOE_RIGHT, 253 -InnerAverageVelocity * InnerAverageVelocity /256);
    analogWrite(nOE, 253 - OuterAverageVelocity * OuterAverageVelocity /256);
  }
  else{
    analogWrite(nOE, 253 -InnerAverageVelocity * InnerAverageVelocity/ 256);
    analogWrite(nOE_RIGHT, 253 - OuterAverageVelocity*OuterAverageVelocity / 256);
  }
  
}

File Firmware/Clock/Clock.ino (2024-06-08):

#include "WiFiCredentials.h"
#include "DisplayPinDefs.h"

#include <WiFi.h>
#include "time.h"

struct tm timeinfo;

void DisplayNumber(int numberToDisplay){
  int firstDigit = numberToDisplay % 10;
  int secondDigit = ((numberToDisplay % 100) - firstDigit)/10;
  int thirdDigit = ((numberToDisplay % 1000 - (secondDigit*10)) - firstDigit)/100;
  int fourthDigit = (numberToDisplay - (thirdDigit * 100) - (secondDigit * 10) - firstDigit)/1000;
  //shift data to 595
  shiftOut(SER, SRCLK, LSBFIRST, displayData[firstDigit]);
  shiftOut(SER, SRCLK, LSBFIRST, displayData[secondDigit]);
  shiftOut(SER, SRCLK, LSBFIRST, displayData[thirdDigit]);
  shiftOut(SER, SRCLK, LSBFIRST, displayData[fourthDigit]);
  //push data to storage register
  digitalWrite(RCLK, HIGH);
  delayMicroseconds(100);
  digitalWrite(RCLK, LOW);
}

void initWifi() {
  // Connect to Wi-Fi
  WiFi.begin(ssid, password);
  while (WiFi.status() != WL_CONNECTED) {
    delay(1000);
    Serial.println("Connecting to WiFi...");
  }
  // Initialize a time structure and set the timezone, e.g., GMT-8
  configTime(-5 * 3600, 3600, "pool.ntp.org", "time.nist.gov");
  Serial.println("Connected to the WiFi network");
}


void setup() {
  Serial.begin(115200);

  pinMode(DISPLAYVDD, OUTPUT);
  digitalWrite(DISPLAYVDD, HIGH);

  pinMode(nOE, OUTPUT);
  pinMode(nCLR, OUTPUT);
  pinMode(SER, OUTPUT);
  pinMode(RCLK, OUTPUT);
  pinMode(SRCLK, OUTPUT);

  digitalWrite(nCLR, HIGH);
  analogWrite(nOE, 254);

  initWifi();
}

int getTime(){

  int timenow;
  if (!getLocalTime(&timeinfo)) {
    Serial.println("Failed to obtain time");
    return 0;
  }
  Serial.println(&timeinfo, "%A, %B %d %Y %H:%M:%S");  // Print the time in a more readable format
  if(timeinfo.tm_hour > 12){
    timenow = (timeinfo.tm_hour % 12) * 100 + timeinfo.tm_min;
  }
  else{
    timenow = (timeinfo.tm_hour) * 100 + timeinfo.tm_min;
  }
  Serial.println(timenow);
  return timenow;
}

void loop() {

  DisplayNumber(getTime());

  if(timeinfo.tm_hour == 1 && millis() > (1000 * 60 * 60 * 23)){
    ESP.restart();
  }

  if((timeinfo.tm_hour == 7 && timeinfo.tm_min >= 30)){
    analogWrite(nOE, 0);
  }
  else if(timeinfo.tm_hour > 7){
    analogWrite(nOE, 127);
  }
  else{
    analogWrite(nOE, 254);
  }

  delay(10000);  // Update every 10 seconds

}

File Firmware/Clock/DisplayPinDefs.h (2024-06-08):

#define SER 16
#define nOE 18
#define RCLK 33
#define SRCLK 35
#define nCLR 37
#define DISPLAYVDD 39

uint8_t displayData[] ={ 
0b10111011,
0b00000011,
0b00111010,
0b00011110,
0b01000110,
0b01011100,
0b00101110,
0b00110010,
0b01111110,
0b01011110
};

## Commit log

2023-02-08 Added STEP files
    [C20SBSN-M89.step]
2023-02-08 changed 1x20 header digikey PN
    [LED_Panel.kicad_pcb, LED_Panel.kicad_sch]
2023-02-08 renamed gerber files for LED panel
2023-02-08 edited header PN
    [LED_Panel.kicad_pcb, LED_Panel.kicad_sch]
2023-02-08 renamed and moved led panel iBOM
2023-02-08 updated gerber names
2023-02-08 updated BOM
    [LED_Panel_Controller.kicad_pcb, LED_Panel_Controller.kicad_sch, LED_Voltage_buck.kicad_sch]
2023-02-08 changed page size, BOM
    [LED_Panel_Controller.kicad_pcb, LED_Panel_Controller.kicad_sch, LED_Voltage_buck.kicad_sch]
2023-02-09 changed VIN cap to 35V rating
    [LED_Panel_Controller.kicad_sch, LED_Voltage_buck.kicad_sch]
2023-02-09 updated readme to use 35V capacitor PN
2023-02-09 corrected resistor PNs
2023-03-14 added firmware for arduino
2023-03-14 maximum voltage changed to 28V
2023-03-30 Changed FW to work with servos
2023-03-30 Created a spacer PCB
    [Spacer.kicad_pcb, Spacer.kicad_sch, Spacer.step]
2023-07-19 updated silk
    [Spacer.kicad_pcb]
